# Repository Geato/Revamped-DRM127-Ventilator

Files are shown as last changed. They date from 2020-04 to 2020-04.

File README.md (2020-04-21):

Revamped-DRM127-Ventilator-PCB
==============================

This is an Altium version of the popular NXP (Freescale) ventilator design
note, DRM127 which was printed in 2010. A lot of groups have been looking
into building the NXP design in view of the Covid-19 pandemic. Unfortunately,
pressure sensors are quite difficult to get as a result.

Please note the component designators are not the same as the original
design because I have added and removed some components. I have also tried
switching to as many SMT components as possible.

The biggest change is the LCD display is mounted on the back of the PCB so
the electronics are all on one board. I have included a mechanical drawing
which should help in making panel cutouts / holes in the front panel of the
case.

The LCD should be mounted on a 0.125” or 3.18mm standoff. To make the
electrical connection, you can use a header like this one:
<https://www.digikey.com/en/products/detail/samtec-inc/TS-116-G-A/1105446>.
Neither of these two parts are listed on the BOM.

Note: the BOM calls for a 4N35. I did not have a library componentfor the 4N27
so I substituted a 4N35 which you can probably use regardless

I cannot take any responsibility for any design issues nor can I
assume any liability for the operation or safety relating to this design.

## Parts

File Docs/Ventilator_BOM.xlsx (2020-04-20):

Line # | Name | Description | Designator | Revision ID | Revision State | Quantity | Manufacturer 1 | Manufacturer Part Number 1 | Manufacturer Lifecycle 1 | Supplier 1 | Supplier Part Number 1 | Supplier Unit Price 1 | Supplier Subtotal 1
 | CAP 100nF 50V 0603(1608) | CAP 100nF 50V ±10% 0603 (1608 Metric) Thickness 1mm SMD | C1, C2, C3, C4, C5, C6, C7, C8, C9, C10, C11, C12, C15, C16, C17, C18, C19, C22, C23, C25, C27 | CMP-1035-02592-1 | Released | 21 | Yageo | CC0603KRX7R9BB104 | Volume Production | Digi-Key | 311-1344-1-ND | 0.069 | 1.45
 | CAP 12pF 50V 0603(1608) | CAP 12pF 50V ±0.5pF 0603 (1608 Metric) Thickness 1mm SMD | C13, C14 | CMP-1035-00616-1 | Released | 2 | KEMET | C0603C120D5GACTU | Volume Production | Digi-Key | 399-10041-1-ND | 0.5 | 1
 | 10µF | CAP ALUM 10UF 20% 25V SMD | C20 |  | Not managed | 1 | Panasonic | EEE-1EA100SR | Volume Production | Digi-Key | PCE3894CT-ND | 0.29 | 0.29
 | 47µF | CAP ALUM 47UF 20% 35V SMD | C21, C24, C26 |  | Not managed | 3 | Nichicon | UWT1V470MCL1GS | Volume Production | Digi-Key | 493-2202-1-ND | 0.38 | 1.14
 | CAP 4.7uF 16V 0805(2012) | CAP 4.7uF 16V ±20% 0805 (2012 Metric) Thickness 1.45mm SMD | C28, C30 | CMP-1036-04891-1 | Released | 2 | KEMET | C0805C475M4PACTU | Volume Production | Digi-Key | 399-9249-1-ND | 0.46 | 0.92
 | CAP 470nF 50V 0805(2012) | CAP 470nF 50V ±10% 0805 (2012 Metric) Thickness 1.45mm SMD | C29 | CMP-1036-04654-1 | Released | 1 | Kyocera AVX | 08055C474KAT2A | Volume Production | Digi-Key | 478-5033-1-ND | 0.44 | 0.44
 | SBR80520LT1G | DIODE SCHOTTKY 20V 500MA SOD123 | D1, D3, D4, D5, D6, D8 |  | Not managed | 6 | ON Semiconductor | SBR80520LT1G | Volume Production | Digi-Key | SBR80520LT1GOSCT-ND | 0.4 | 2.4
 | TLHK5800 | T-13/4 LED | D2 |  | Not managed | 1 | Vishay Semiconductors | TLHK5800 | Volume Production | Digi-Key | 751-1119-ND | 0.45 | 0.45
 | Yellow | LED YELLOW DIFFUSED 0603 SMD | D7 |  | Not managed | 1 | Dialight | 597-5223-407F | Not Recommended for New Design | Digi-Key | 350-3032-1-ND | 1.87 | 1.87
 | S8MC-13 | DIODE GEN PURP 1KV 8A SMC | D9 |  | Not managed | 1 | Diodes | S8MC-13 | Volume Production | Digi-Key | S8MCDICT-ND | 0.61 | 0.61
 | SMCJ13A-13-F | TVS DIODE 13V 21.5V SMC | D10 |  | Not managed | 1 | Diodes | SMCJ13A-13-F | Volume Production | Digi-Key | SMCJ13A-13-FDICT-ND | 0.66 | 0.66
 | 270 Ohms @ 100MHz | FERRITE BEAD 270 OHM 0603 1LN | FB1, FB2 |  | Not managed | 2 | Taiyo Yuden | BKP1608HS271-T | Volume Production | Digi-Key | 587-1925-1-ND | 0.1 | 0.2
 | 220 Ohms @ 100MHz | FERRITE BEAD 220 OHM 0805 1LN | FB3, FB4, FB5 |  | Not managed | 3 | Murata | BLM21PG221SN1D | Volume Production | Digi-Key | 490-1054-1-ND | 0.1 | 0.3
 | 67503-1020 | USB, MINI, SMD, RA KME04-USBMU03A01 | J1 | CMP-0411-00002-1 | Released | 1 | Molex | 67503-1020 | Volume Production | Digi-Key | WM5461CT-ND | 1.08 | 1.08
 | 1725656 | Male Header, Pitch 2.54 mm, 1 x 2 Position, Height 9 mm, Tail Length 3.5 mm | J2, J3, J4, J5, J6, J7 | CMP-2000-05299-1 | Released | 6 | Phoenix Contact | 1725656 | Volume Production | Digi-Key | 277-1273-ND | 1.65 | 9.9
 | JSM1-12V-5 | Global Standard Terminal Pitch Automotive Power Relay, SPDT, 12 VDC, -40 to 85 degC, 5-Pin THD, RoHS, Bulk | K1 | CMP-2000-06504-1 | Released | 1 | Panasonic | JSM1-12V-5 | Volume Production | Digi-Key | 255-1240-ND | 1.68 | 1.68
 | CSQG703BP | Loudspeaker | LS1 |  | Not managed | 1 | CUI | CSQG703BP | Volume Production | Digi-Key | 102-1286-ND | 0.83 | 0.83
 | Header 16 | Header, 16-Pin | P1 |  | Not managed | 1 | Amphenol FCI | 68000-416HLF | Volume Production | Digi-Key | 609-3267-ND | 0.55 | 0.55
 | Header 3X2 | Header, 3-Pin, Dual row | P2, P3 |  | Not managed | 2 | 3M | 929836-01-03 | Volume Production | Digi-Key | 3M156447-06-ND | 0.62 | 1.24
 | MMBTA06-7-F | NPN Small Signal Transistor, 80 V, -55 to 150 degC, 3-Pin SOT23, RoHS, Tape and Reel | Q1 | CMP-2000-06733-1 | Released | 1 | Diodes | MMBTA06-7-F | Volume Production | Digi-Key | MMBTA06-FDICT-ND | 0.21 | 0.21
 | FDS6690A | Single N-Channel, Logic-Level, PowerTrench(R) MOSFET, 11 A, 30 V, -55 to 150 degC, 8-Pin SOIC (SO-8), RoHS, Tape and Reel | Q2, Q3, Q4, Q5 | CMP-2000-06260-1 | Released | 4 | ON Semiconductor / Fairchild | FDS6690A | Volume Production | Digi-Key | FDS6690ACT-ND | 0.66 | 2.64
 | 10K 5% 0603(1608) | 10K 0.1W 5% 0603 (1608 Metric) SMD | R1, R4, R8, R9, R11, R14, R15, R19, R20, R24, R26 | CMP-1012-00098-1 | Released | 11 | Vishay Dale | CRCW060310K0JNEA | Volume Production | Digi-Key | 541-10KGCT-ND | 0.031 | 0.341
 | 10K | TRIMMER 10K OHM 0.1W J LEAD TOP | R2 |  | Not managed | 1 | Bourns | TC33X-1-103E | Volume Production | Digi-Key | TC33X-1-103ECT-ND | 0.28 | 0.28
 | 330R 5% 0603(1608) | 330R 0.1W 5% 0603 (1608 Metric) SMD | R3, R6, R10, R13, R18, R27 | CMP-1012-00062-1 | Released | 6 | Yageo | RC0603JR-07330RL | Volume Production | Digi-Key | 311-330GRCT-ND | 0.019 | 0.19
 | 220R 5% 0603(1608) | 220R 0.1W 5% 0603 (1608 Metric) SMD | R5 | CMP-1012-00058-1 | Released | 1 | Yageo | RC0603JR-07220RL | Volume Production | Digi-Key | 311-220GRCT-ND | 0.1 | 0.1
 | 100R 5% 0603(1608) | 100R 0.1W 5% 0603 (1608 Metric) SMD | R7, R12, R17, R22 | CMP-1012-00050-1 | Released | 4 | Yageo | RC0603JR-07100RL | Volume Production | Digi-Key | 311-100GRCT-ND | 0.019 | 0.19
 | 169K 1% 0603(1608) | 169K 0.1W 1% 0603 (1608 Metric) SMD | R16, R23 | CMP-1012-00760-1 | Released | 2 | Yageo | RC0603FR-07169KL | Volume Production | Digi-Key | 311-169KHRCT-ND | 0.1 | 0.2
 | 330K 1% 0603(1608) | 330K 0.1W 1% 0603 (1608 Metric) SMD | R21, R25 | CMP-1012-00793-1 | Released | 2 | Yageo | RC0603FR-07330KL | Volume Production | Digi-Key | 311-330KHRCT-ND | 0.1 | 0.2
 | 180R 5% 0603(1608) | 180R 0.1W 5% 0603 (1608 Metric) SMD | R28 | CMP-1012-00056-1 | Released | 1 | Yageo | RC0603JR-07180RL | Volume Production | Digi-Key | 311-180GRCT-ND | 0.1 | 0.1
 | 22R 5% 0603(1608) | 22R 0.1W 5% 0603 (1608 Metric) SMD | R29, R30 | CMP-1012-00034-1 | Released | 2 | Yageo | RC0603JR-0722RL | Volume Production | Digi-Key | 311-22GRCT-ND | 0.019 | 0.19
 | B3S-1000P | SWITCH TACTILE SPST-NO 0.05A 24V | S1 |  | Not managed | 1 | Omron | B3S-1000P | Volume Production | Digi-Key | SW836CT-ND | 0.8 | 0.8
 | EP11SD1CBE | EP Series Sealed Pushbutton Switches | SW1, SW2, SW3, SW4 |  | Not managed | 4 | ITT C&K | EP11SD1CBE | Volume Production | Digi-Key | CKN4006-ND | 5.07 | 20.28
 | MCF51MM256CLL | 32-bit Coldfire Freescale MCU | U1 |  | Not managed | 1 | NXP Freescale | MCF51MM256CLL | Volume Production | Digi-Key | 568-14492-ND | 10.97 | 10.97
 | LM94021BIMG | Multi-Gain Analog Temperature Sensor, 5-pin SC-70 | U2 | CMP-0066-00198-3 | Released | 1 | TI National Semiconductor | LM94021BIMG | Volume Production
 | MP3V5050GP |  | U3, U4 |  | Not managed | 2 | NXP Freescale | MP3V5050GP | Volume Production
 | MPXV7025DP | +/- 25 kPa Differential Pressure Sensor | U5, U6 |  | Not managed | 2 | NXP Freescale | MPXV7025DP | Volume Production | NAC Semi | XSFP00000174333 | 11.34 | 283.5
 | 4N35 | 6Pin Optocoupler | U7 |  | Not managed | 1
 | LM1085ISX-5.0/NOPB | 3A Low Dropout Positive Regulators, 3-pin TO-263, Pb-Free | U8 | CMP-0062-00617-5 | Released | 1 | TI National Semiconductor | LM1085ISX-5.0/NOPB | Volume Production | Digi-Key | 296-35391-1-ND | 1.97 | 1.97
 | LD1117S33CTR | Fixed Low Drop Positive Voltage Regulator, 3.3V, 4-Pin SOT-223, Tape and Reel | U9 | CMP-0244-00307-1 | Released | 1 | STMicroelectronics | LD1117S33CTR | Volume Production | Digi-Key | 497-1241-1-ND | 0.41 | 0.41
 | CX2520DB16000D0GEJCC | Crystal, 16 MHz, 8 pF, -10 to 70 degC, 4-Pin SMD, RoHS, Tape and Reel | X1 | CMP-2000-06128-1 | Released | 1 | Kyocera AVX | CX2520DB16000D0GEJCC | Volume Production | Digi-Key | 1253-1122-1-ND | 0.92 | 0.92

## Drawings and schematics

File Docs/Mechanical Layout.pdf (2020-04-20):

## C24C²¹

# 3.00mm⁷¹.00mm 68.00mm

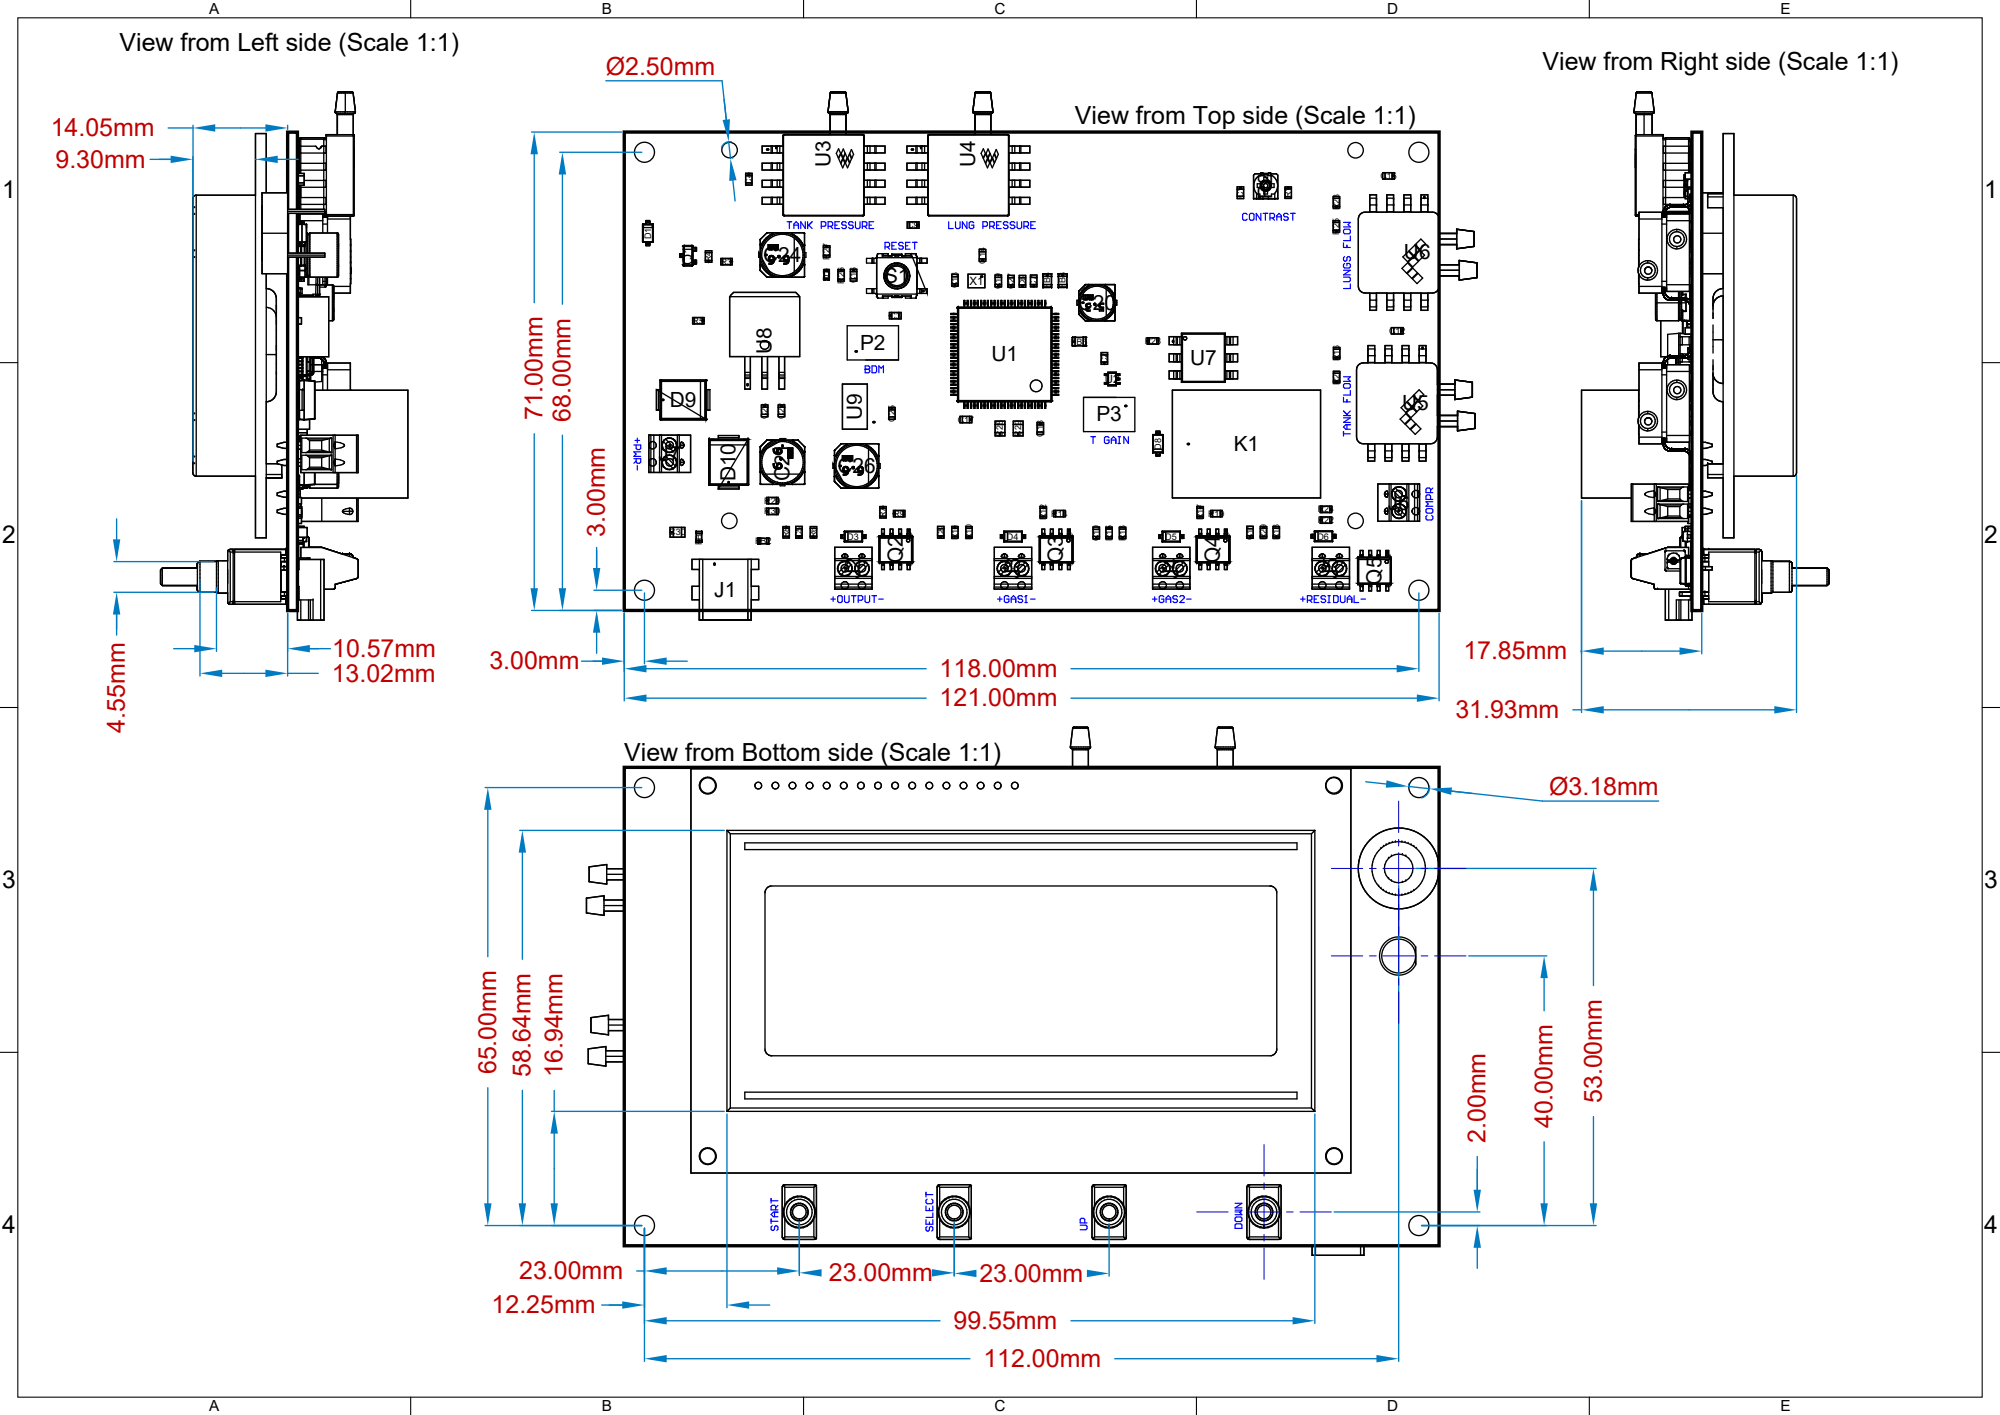
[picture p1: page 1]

View from Left side (Scale 1:1)

View from Right side (Scale 1:1)

View from Top side (Scale 1:1)

View from Bottom side (Scale 1:1)

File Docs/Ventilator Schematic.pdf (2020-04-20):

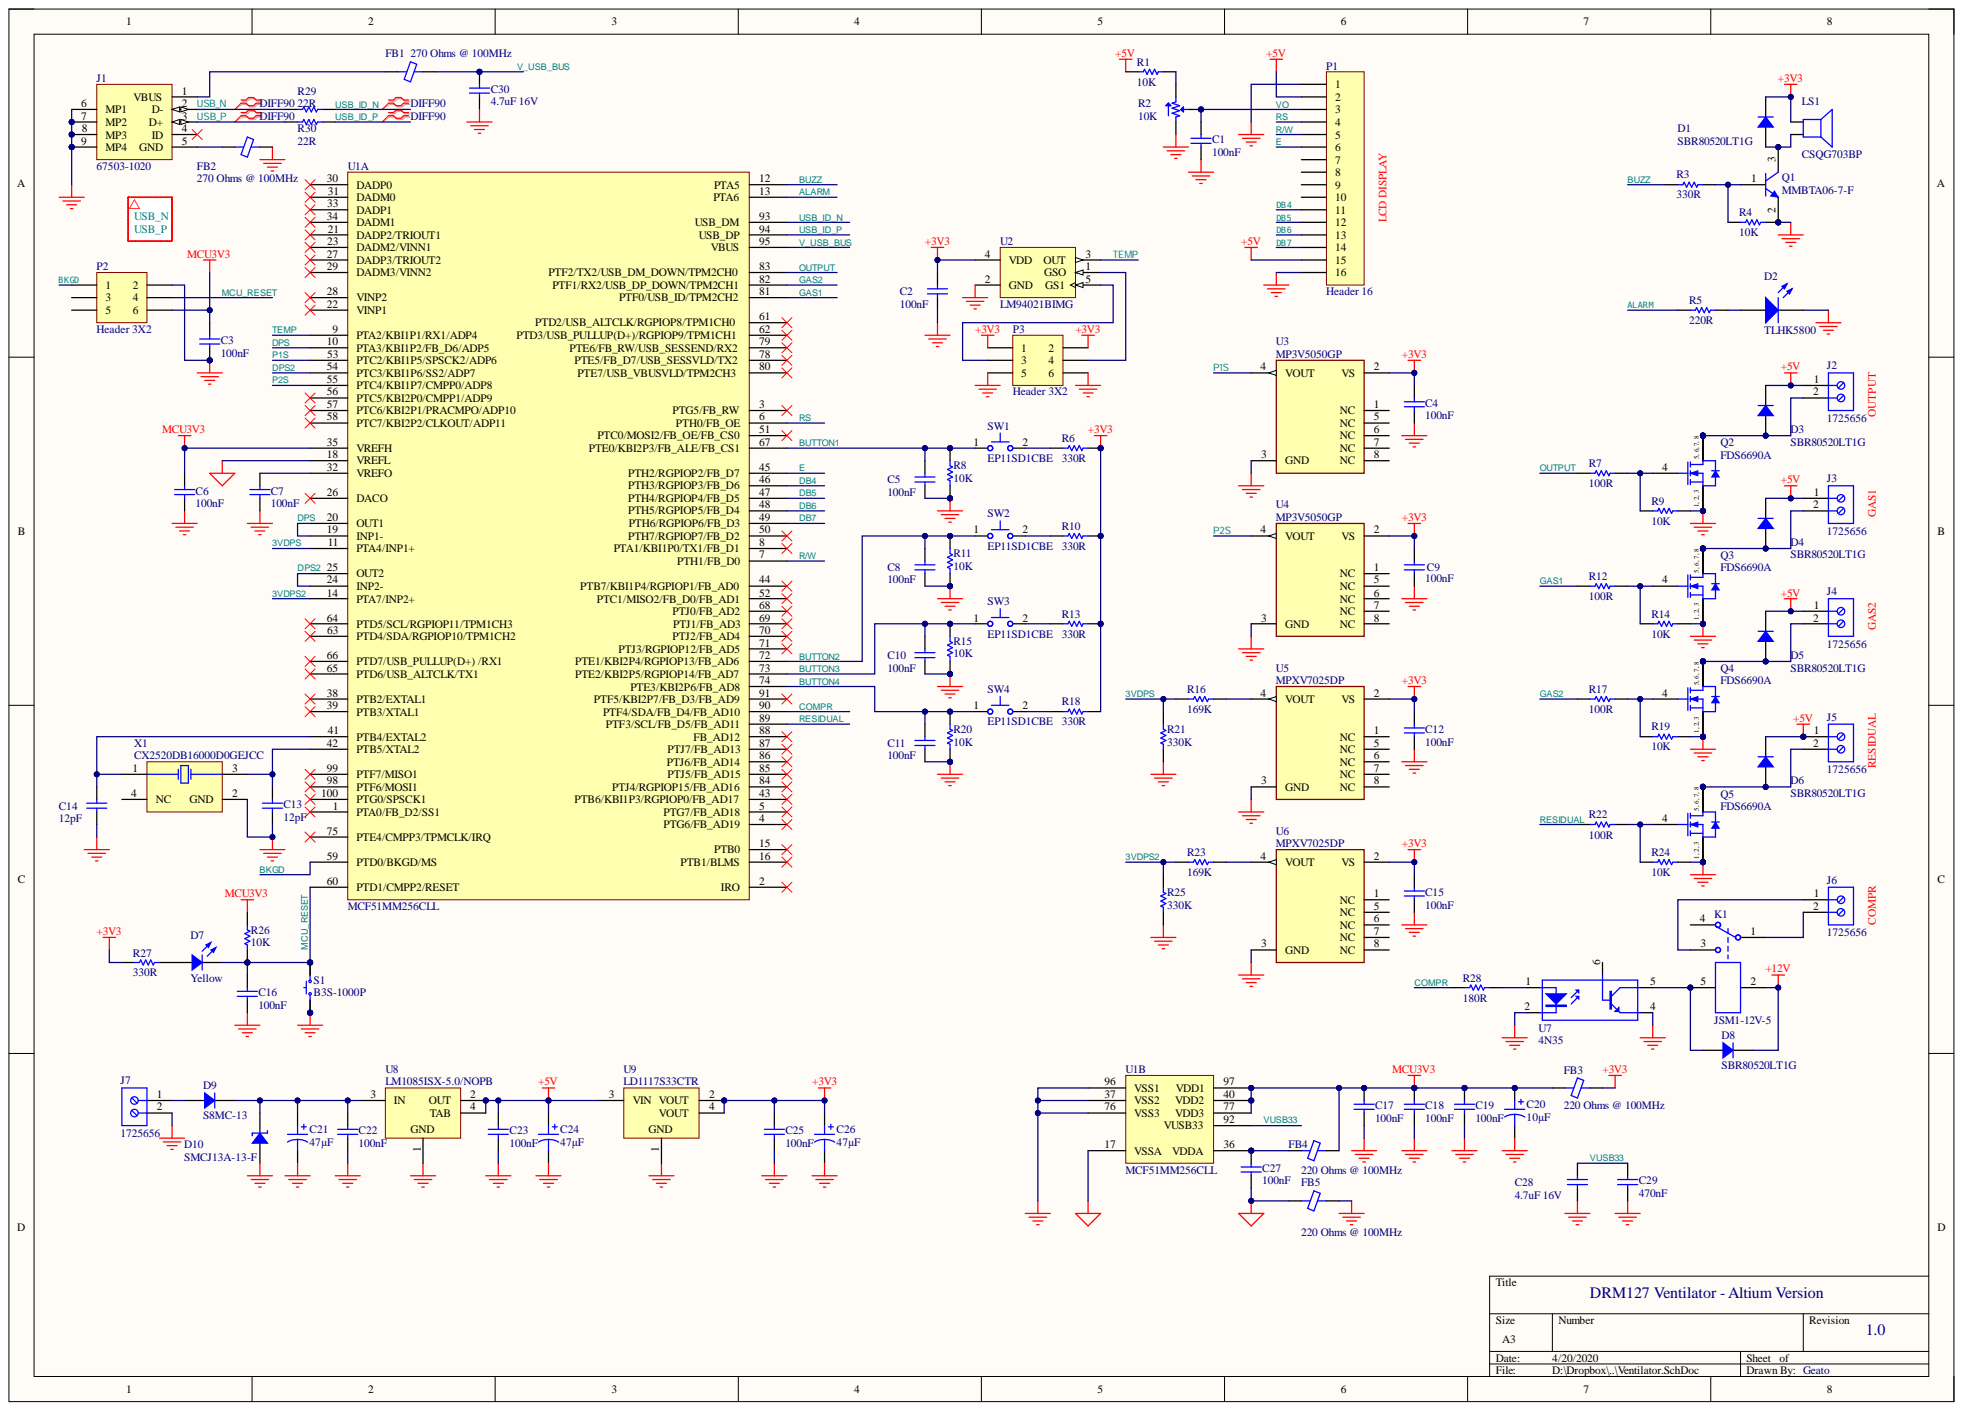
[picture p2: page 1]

7 | 3 USB _P D IFF90
